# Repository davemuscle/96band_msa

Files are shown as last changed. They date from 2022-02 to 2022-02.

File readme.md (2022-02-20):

# 96 Note Music Spectrum Analyzer - FPGA

GIF

*Migrated to Git on February 20th, 2022. Updated web page on July 5th, 2020. Original release in
April 2020.*

This project converts your audio into a frequency spectrum and displays it on a VGA monitor in
real-time. The spectrum is mapped to all 96 half-notes in the first eight octaves, and is tuned to
A4 (440 Hz). It provides a visible output of 1920x1080 pixels at 60FPS, including multiple color
palette choices. There is also a choice between using an onboard microphone with auto gain control,
or a line-level input output pair.

All of the code was written in VHDL on an Artix-7. The main DSP technique used was multi-resolution,
constant-Q analysis. A custom PCB was designed at the end of project.

The general timeframe was between December 2019 and April 2020. This includes multiple rewrites of
the entire VHDL codebase, multiple hardware choice changes, and the design of the website.

## Demonstration
CTRL+click the video thumbnails to open in a new tab

| Youtube Videos |
| :--: |
| *Music Spectrum Analyzer - OSRS Harmony* |
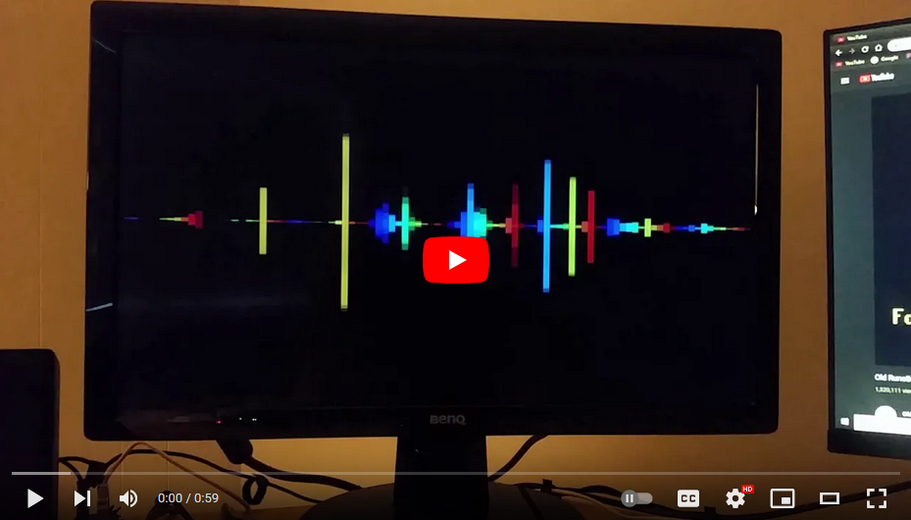
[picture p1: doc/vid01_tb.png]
(https://youtu.be/-Q9aSZRLyek)
|  |
| *Music Spectrum Analyzer - Ave Maria* |
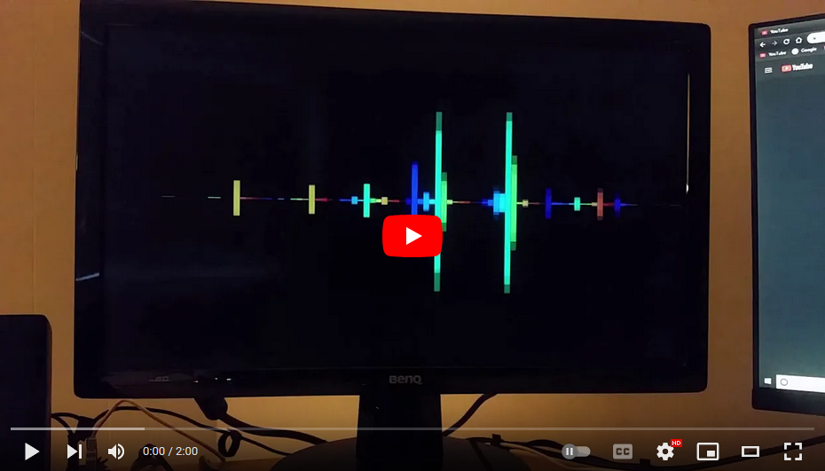
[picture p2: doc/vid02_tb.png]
(https://youtu.be/DIGgBtx7Qf0)
|  |
| *Music Spectrum Analyzer - Davy Jones Theme* |
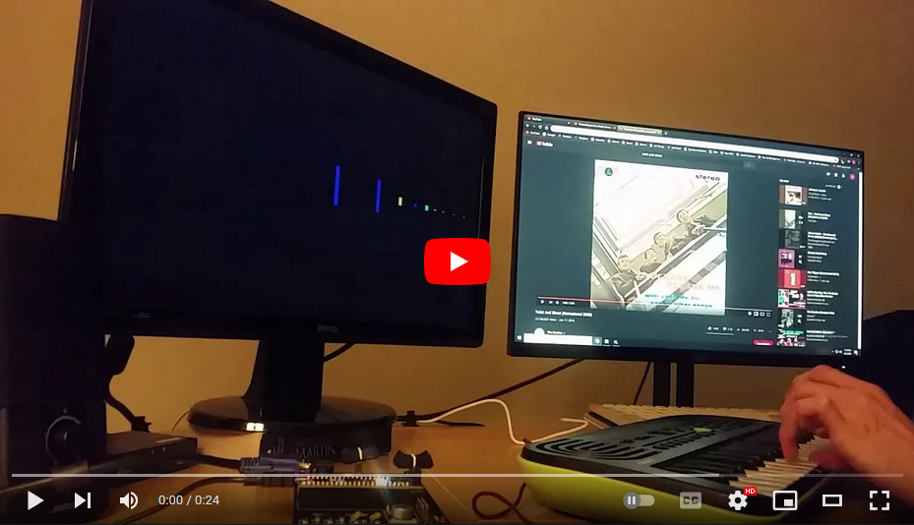
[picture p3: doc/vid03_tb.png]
(https://youtu.be/745tQkoyp0c)
|  |

## Implementation
### Hardware Block Diagram

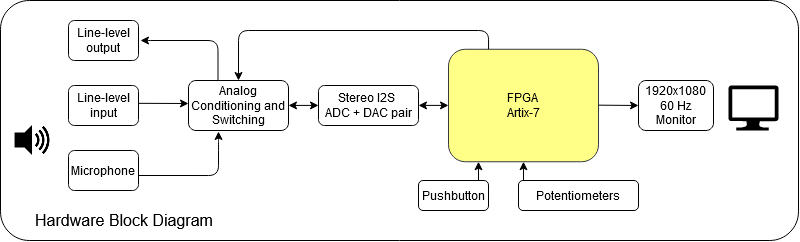
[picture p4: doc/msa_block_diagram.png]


### Printed Circuit Board

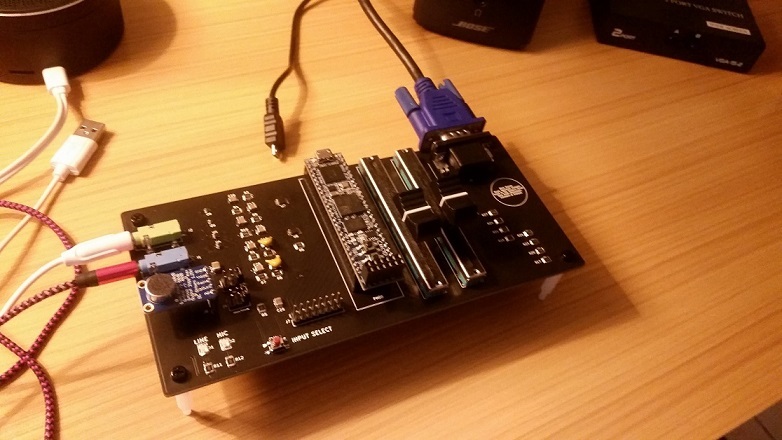
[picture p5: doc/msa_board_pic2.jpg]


### FPGA Design

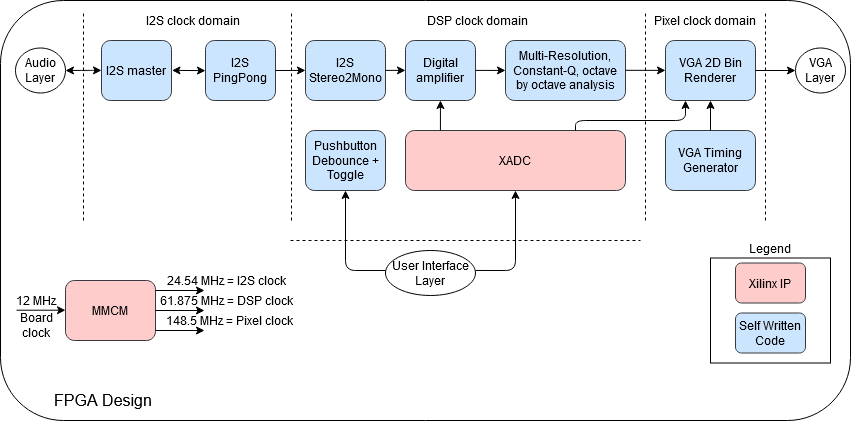
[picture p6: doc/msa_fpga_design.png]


#### Sub-designs
- I2S Master
    - Interface to I2S audio layer, reads and writes one sample of sound.
- I2S PingPong
    - Buffers up a selectable amount of audio in ping-pong fashion. Allows reading and writing
      blocks of sound to the audio layer.
- I2S Stereo2Mono
    - Converts stereo audio to mono audio
- Digital Amplifier
    - Multiplies sound data by a scalar factor based on XADC input
- Multi-Resolution Analysis
    - See below
- VGA Timing Generator
    - Creates sync signals based on screen resolution and framerate.
- VGA 2D Bin Renderer
    - Draws the frequency spectrum on the screen

### DSP Processing

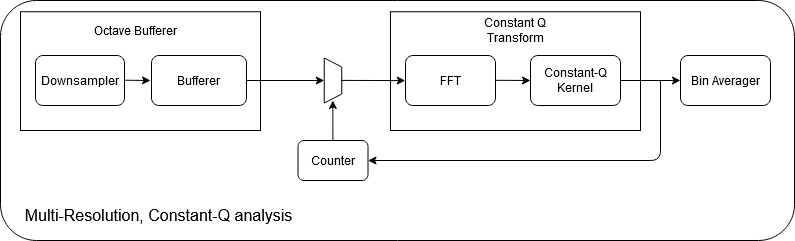
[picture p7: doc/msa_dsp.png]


The first portion of the DSP process downsamples the mono audio at 48 kHz into 8 separate octaves.
The downsampled data is buffered up, and a 256-point FFT followed by a Constant-Q transform is
performed on each octave. This downsampling and buffering is what gives us the "multi-resolution"
part of the project. The resulting frequency bins are averaged together to match the monitor's
refresh rate.

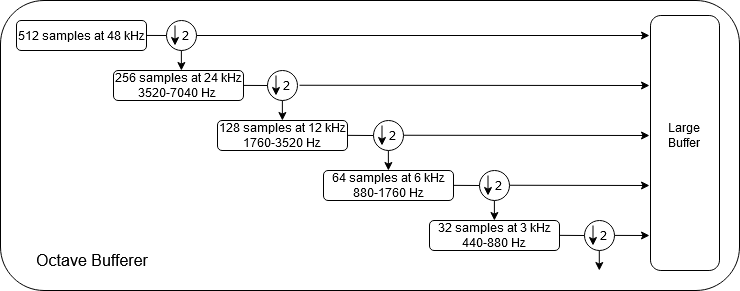
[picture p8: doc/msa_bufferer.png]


Above is the diagram for the octave bufferer. 512 samples at 48 kHz are sequentially downsampled
until we get to the loweset octave of interest.

### Reasoning behind Multi-Resolution Analysis

We actually perceive sound on a logarithmic scale, and we already are using multi-resolution
analysis! Our ears naturally have good time-localization for high-frequency sounds, and good frequency
resolution for low-frequency sounds. This means we can better determine when high-frequency sounds 
occur (time localization) and we can better distinguish between low frequency sounds (frequency resolution).

Check out the time-frequency tiling diagram:

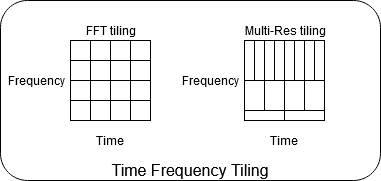
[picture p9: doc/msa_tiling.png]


The x-axis for each box represents a slice of time over which an FFT or some other process is
performed. The y-axis represents the frequency resolution for that time chunk.

The left diagram is how most spectrum analyzers are made -- with just an FFT. All of the tiles have
constant frequency and time resolution. 

The right is how I designed mine, attempting to match how we hear. Recording more samples allows for
a greater frequency resolution, but at the cost of higher latency. This means the lower frequencies
on the screen won't be as responsive as the higher frequencies.

The benefit to downsampling and processing multiple octaves separately is that the same sized FFT
can be used for each octave, and resources aren't wasted on the higher frequencies.

### Reasoning behind the Constant-Q Transform

Take a look at the difference in the piano keys below:

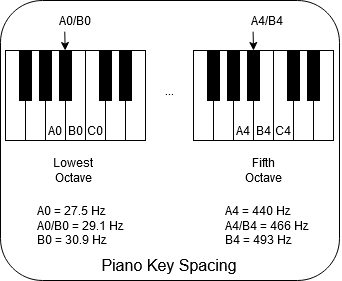
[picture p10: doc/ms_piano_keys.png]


The difference between the two lowest notes on an 88-key piano is only 1.6Hz, but for the fifth
octave, the difference in the lowest notes is 26 Hz!

This is because musical notes are logarithmically spaced, just like our hearing.
Each note can be obtained from another note by multiplying by a factor of 2^(1/12).

An FFT isn't great for this, since the frequency bins are arithmetically spaced (50 Hz, 100 Hz, ...)
The Constant-Q transform IS great for this, since we can specify a geometric scale to output our
bins.

The efficient implementation of the Constant-Q transform is pretty straight forward:
Generate the kernel for the transform (a sparse matrix of    coefficients, can be done before
run-time)
Take the FFT of your data 
Apply the generated kernel (this is just a matrix-multiply)

I pasted the code for the direct form of the Constant-Q transform below. If you interested in the
efficient implementation, check out the references.

### MATLAB Code for the Constant-Q Transform (Direct-Form)
```
%input setup
fs = 4000;                         %sample rate
note = 440;                        %note frequency, A4
input = cos(2*pi*note*(0:511)/fs); %pure tone input

%fft setup
fft_output = zeros(1, length(input)); %output vector
N = length(input);                    %size

%fft direct form = dft (slow)
for k = 0:N-1
    fft_output(k+1) = input * exp(-2*pi*1i*k*(0:N-1)'/N); %complex mult + LUT
end

%cqt setup
minimum_freq = 220;                                        %two full octaves are specified between
maximum_freq = 880;                                        %the min and the max frequencies
bins_per_octave = 12;                                      %12 bins per octave = 1 bin for 1 note
Q = 1/(2^(1/bins_per_octave)-1);                           %Q factor of the filterbank
K = ceil(bins_per_octave*log2(maximum_freq/minimum_freq)); %total num bins
cqt_output = zeros(1,K);

%cqt direct form
%this is the slow way to calculate the cqt
for k = 1:K
   N = round(Q*fs/(minimum_freq*2^((k-1)/bins_per_octave)));    %variable length
   cqt_output(k) = cqt_input(1:N) * exp(-2*pi*1i*Q*(0:N-1)'/N); %same form as fft
end

%plots of obtained data obtained
close all;
figure %only plotting one image of the spectrum
stem(abs(fft_output(1:length(input)/2)))
title('fft output');
ylabel('magnitude');
xlabel('bin');
figure
stem(abs(cqt_output))
title('cqt output');
ylabel('magnitude');
xlabel('bin');
```
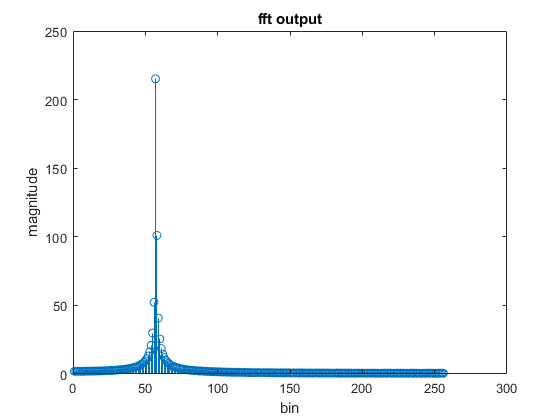
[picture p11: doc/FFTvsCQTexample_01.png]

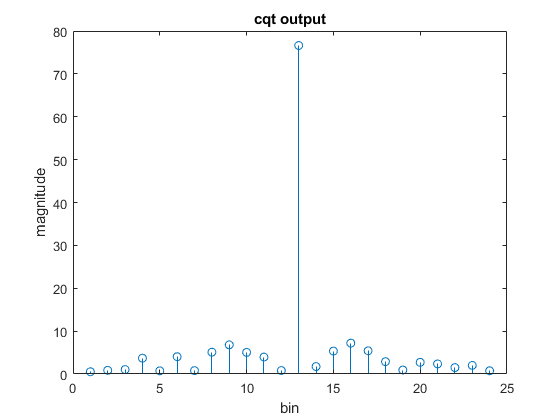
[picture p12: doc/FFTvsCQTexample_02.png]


### References
1. [Piano Key Frequencies](https://en.wikipedia.org/wiki/Piano_key_frequencies)
2. [Benjamin Blankertz, Constant-Q Transform](http://doc.ml.tu-berlin.de/bbci/material/publications/Bla_constQ.pdf)
3. [Brown & Puckette , Effecient Constant-Q Transform](http://academics.wellesley.edu/Physics/brown/pubs/effalgV92P2698-P2701.pdf)
4. [Djikstra's Square Root Algorithm](http://lib.tkk.fi/Diss/2005/isbn9512275279/article3.pdf)
5. [VGA Timing](https://projectf.io/posts/video-timings-vga-720p-1080p/)
6. [Artix 7 Board](https://digilent.com/shop/cmod-a7-breadboardable-artix-7-fpga-module/)
7. [Website Inspiration, 96khz.org](http://www.96khz.org/projects.htm)

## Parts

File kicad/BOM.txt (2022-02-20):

Components per board:

Core
	1 CMOD A7

Mechanical

	2 Slidepots
	1 Push button
	4 Mounting Pads

Capacitors (all 1210 - 3225 metric)
	14 	100 nF
	5  	10 uF
	6 	1 uF
	2 	3.3 uF
	2 	180 pF
	2	2.7 nF
	1	100 uF
	
Resistors (all 1210 - 3225 metric)
	6	4.7k
	4   	10k
	5 	470
	5	1k
	3	2.2K

LEDs (all 1210 - 3225 metric)
	2 	LEDs (blue?)
	
ICs
	1	3.3V voltage reg
	4	analog switches
	1 	adc
	1	dac

Connectors
	2 	Audio Jacks (1 green, 1 blue)
	Assortment of cuttable male and female headers
	1	VGA DB15

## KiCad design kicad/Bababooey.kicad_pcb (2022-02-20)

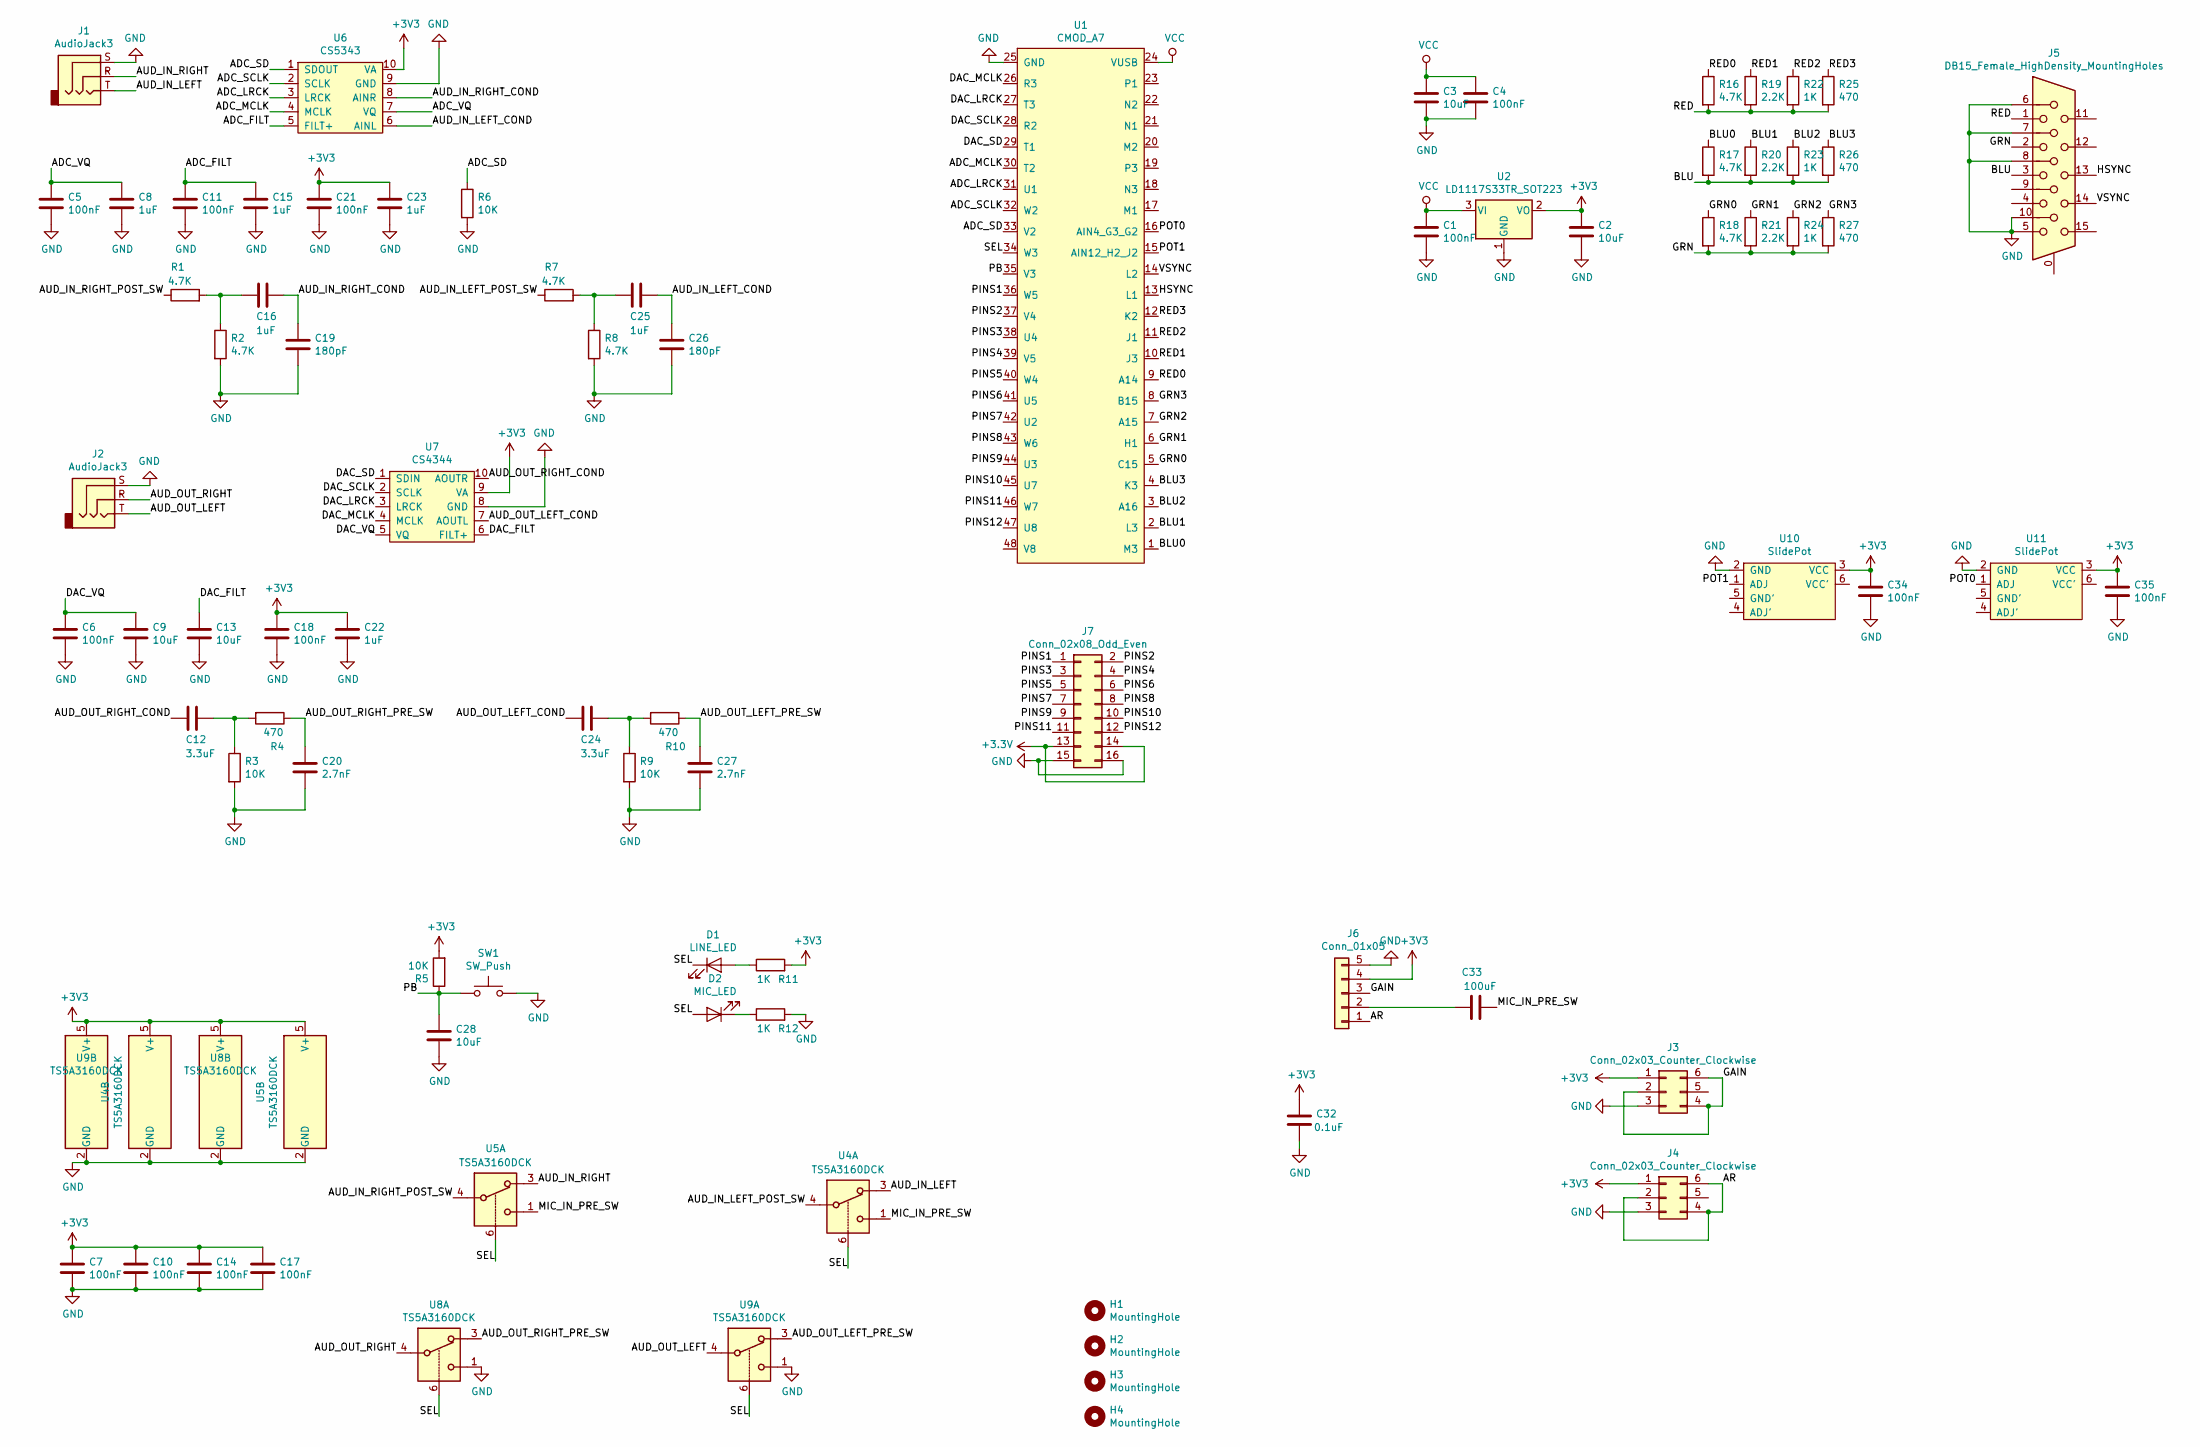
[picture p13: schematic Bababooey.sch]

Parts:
C1, C4, C5, C6, C7, C10, C11, C14, C17, C18, C21, C34, C35: 100nF; C_1210_3225Metric_Pad1.42x2.65mm_HandSolder
C2, C3, C9, C13, C28: 10uF; C_1210_3225Metric_Pad1.42x2.65mm_HandSolder
C8, C15, C16, C22, C23, C25: 1uF; C_1210_3225Metric_Pad1.42x2.65mm_HandSolder
C12, C24: 3.3uF; C_1210_3225Metric_Pad1.42x2.65mm_HandSolder
C19, C26: 180pF; C_1210_3225Metric_Pad1.42x2.65mm_HandSolder
C20, C27: 2.7nF; C_1210_3225Metric_Pad1.42x2.65mm_HandSolder
C32: 0.1uF; C_1210_3225Metric_Pad1.42x2.65mm_HandSolder
C33: 100uF; C_1210_3225Metric_Pad1.42x2.65mm_HandSolder
D1: LINE_LED; LED_1210_3225Metric_Pad1.42x2.65mm_HandSolder
D2: MIC_LED; LED_1210_3225Metric_Pad1.42x2.65mm_HandSolder
H1, H2, H3, H4: MountingHole; MountingHole_3.5mm
J1, J2: AudioJack3; Jack_3.5mm_CUI_SJ-3524-SMT_Horizontal
J3, J4: Conn_02x03_Counter_Clockwise; PinHeader_2x03_P2.54mm_Vertical
J5: DB15_Female_HighDensity_MountingHoles; DSUB-15-HD_Female_Horizontal_P2.29x1.98mm_EdgePinOffset8.35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
J6: Conn_01x05; PinSocket_1x05_P2.54mm_Vertical
J7: Conn_02x08_Odd_Even; PinSocket_2x08_P2.54mm_Vertical
R1, R2, R7, R8, R16, R17, R18: 4.7K; R_1210_3225Metric_Pad1.42x2.65mm_HandSolder
R3, R5, R6, R9: 10K; R_1210_3225Metric_Pad1.42x2.65mm_HandSolder
R4, R10, R25, R26, R27: 470; R_1210_3225Metric_Pad1.42x2.65mm_HandSolder
R11, R12, R22, R23, R24: 1K; R_1210_3225Metric_Pad1.42x2.65mm_HandSolder
R19, R20, R21: 2.2K; R_1210_3225Metric_Pad1.42x2.65mm_HandSolder
SW1: SW_Push; SW_SPST_TL3305B
U1: CMOD_A7
U2: LD1117S33TR_SOT223; SOT-223-3_TabPin2
U4, U5, U8, U9: TS5A3160DCK; SOT-363_SC-70-6
U6: CS5343; TSSOP-10_3x3mm_P0.5mm
U7: CS4344; TSSOP-10_3x3mm_P0.5mm
U10, U11: SlidePot

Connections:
/ADC_FILT: C11.1, C15.1, U6.5 (FILT+)
/ADC_LRCK: U1.31 (U1), U6.3 (LRCK)
/ADC_MCLK: U1.30 (T2), U6.4 (MCLK)
/ADC_SCLK: U1.32 (W2), U6.2 (SCLK)
/ADC_SD: R6.1, U1.33 (V2), U6.1 (SDOUT)
/ADC_VQ: C5.1, C8.1, U6.7 (VQ)
/AR: J4.2, J4.4, J4.6, J6.1
/AUD_IN_LEFT: J1.T, U4.3
/AUD_IN_LEFT_COND: C25.1, C26.1, U6.6 (AINL)
/AUD_IN_LEFT_POST_SW: R7.1, U4.4
/AUD_IN_RIGHT: J1.R, U5.3
/AUD_IN_RIGHT_COND: C16.1, C19.1, U6.8 (AINR)
/AUD_IN_RIGHT_POST_SW: R1.1, U5.4
/AUD_OUT_LEFT: J2.T, U9.4
/AUD_OUT_LEFT_COND: C24.2, U7.7 (AOUTL)
/AUD_OUT_LEFT_PRE_SW: C27.1, R10.1, U9.3
/AUD_OUT_RIGHT: J2.R, U8.4
/AUD_OUT_RIGHT_COND: C12.2, U7.10 (AOUTR)
/AUD_OUT_RIGHT_PRE_SW: C20.1, R4.1, U8.3
/BLU: J5.3, R17.2, R20.2, R23.2, R26.2
/BLU0: R17.1, U1.1 (M3)
/BLU1: R20.1, U1.2 (L3)
/BLU2: R23.1, U1.3 (A16)
/BLU3: R26.1, U1.4 (K3)
/DAC_FILT: C13.1, U7.6 (FILT+)
/DAC_LRCK: U1.27 (T3), U7.3 (LRCK)
/DAC_MCLK: U1.26 (R3), U7.4 (MCLK)
/DAC_SCLK: U1.28 (R2), U7.2 (SCLK)
/DAC_SD: U1.29 (T1), U7.1 (SDIN)
/DAC_VQ: C6.1, C9.1, U7.5 (VQ)
/GAIN: J3.2, J3.4, J3.6, J6.3
/GRN: J5.2, R18.2, R21.2, R24.2, R27.2
/GRN0: R18.1, U1.5 (C15)
/GRN1: R21.1, U1.6 (H1)
/GRN2: R24.1, U1.7 (A15)
/GRN3: R27.1, U1.8 (B15)
/HSYNC: J5.13, U1.13 (L1)
/MIC_IN_PRE_SW: C33.2, U4.1, U5.1
/PB: C28.1, R5.1, SW1.1, U1.35 (V3)
/PINS1: J7.1, U1.36 (W5)
/PINS2: J7.2, U1.37 (V4)
/PINS3: J7.3, U1.38 (U4)
/PINS4: J7.4, U1.39 (V5)
/PINS5: J7.5, U1.40 (W4)
/PINS6: J7.6, U1.41 (U5)
/PINS7: J7.7, U1.42 (U2)
/PINS8: J7.8, U1.43 (W6)
/PINS9: J7.9, U1.44 (U3)
/PINS10: J7.10, U1.45 (U7)
/PINS11: J7.11, U1.46 (W7)
/PINS12: J7.12, U1.47 (U8)
/POT0: U1.16 (AIN4_G3_G2), U11.1 (ADJ)
/POT1: U1.15 (AIN12_H2_J2), U10.1 (ADJ)
/RED: J5.1, R16.2, R19.2, R22.2, R25.2
/RED0: R16.1, U1.9 (A14)
/RED1: R19.1, U1.10 (J3)
/RED2: R22.1, U1.11 (J1)
/RED3: R25.1, U1.12 (K2)
/SEL: D1.1 (K), D2.2 (A), U1.34 (W3), U4.6, U5.6, U8.6, U9.6
/VSYNC: J5.14, U1.14 (L2)
GND: C1.2, C2.2, C3.2, C4.2, C5.2, C6.2, C7.2, C8.2, C9.2, C10.2, C11.2, C13.2, C14.2, C15.2, C17.2, C18.2, C19.2, C20.2, C21.2, C22.2, C23.2, C26.2, C27.2, C28.2, C32.2, C34.2, C35.2, J1.S, J2.S, J3.3, J4.3, J5.5, J5.6, J5.7, J5.8, J5.10, J6.5, J7.15, J7.16, R2.2, R3.2, R6.2, R8.2, R9.2, R12.2, SW1.2, U1.25 (GND), U2.1 (GND), U4.2 (GND), U5.2 (GND), U6.9 (GND), U7.8 (GND), U8.1, U8.2 (GND), U9.1, U9.2 (GND), U10.2 (GND), U11.2 (GND)
unnamed: C12.1, R3.1, R4.2
unnamed: C16.2, R1.2, R2.1
unnamed: C24.1, R9.1, R10.2
unnamed: C25.2, R7.2, R8.1
unnamed: C33.1, J6.2
unnamed: D1.2 (A), R11.1
unnamed: D2.1 (K), R12.1
VCC: C1.1, C3.1, C4.1, U1.24 (VUSB), U2.3 (VI)

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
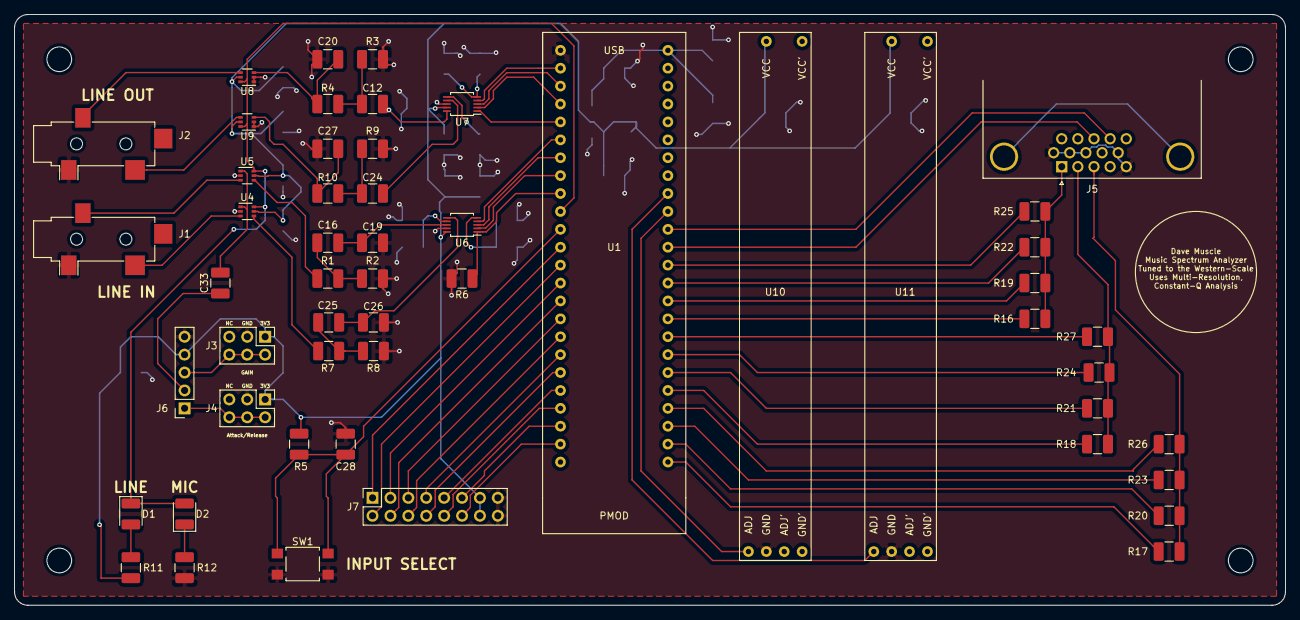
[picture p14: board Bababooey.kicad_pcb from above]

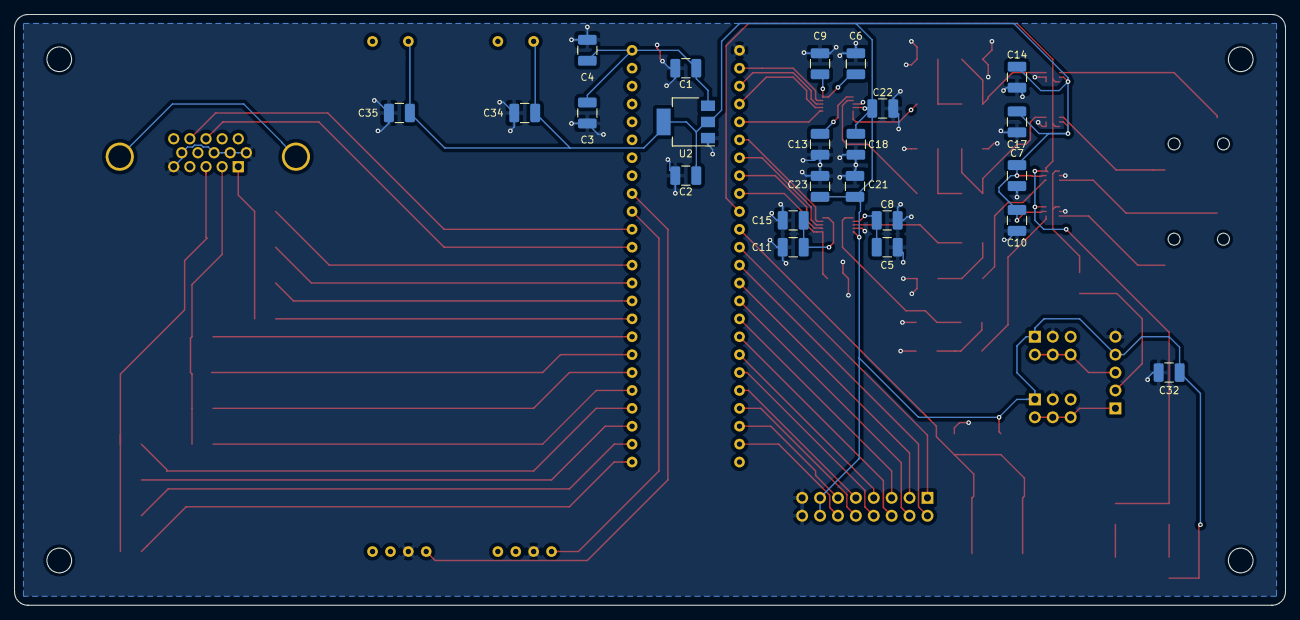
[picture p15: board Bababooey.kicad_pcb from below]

Board: 2 copper layers, 180.3 x 83.8 mm, 80 parts (23 on the bottom side), 70 nets.

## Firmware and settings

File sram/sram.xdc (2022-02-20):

## Cellular RAM
set_property -dict { PACKAGE_PIN M18   IOSTANDARD LVCMOS33 } [get_ports { MemAdr[0]  }]; #IO_L11P_T1_SRCC_14 Sch=sram- a[0]
set_property -dict { PACKAGE_PIN M19   IOSTANDARD LVCMOS33 } [get_ports { MemAdr[1]  }]; #IO_L11N_T1_SRCC_14 Sch=sram- a[1]
set_property -dict { PACKAGE_PIN K17   IOSTANDARD LVCMOS33 } [get_ports { MemAdr[2]  }]; #IO_L12N_T1_MRCC_14 Sch=sram- a[2]
set_property -dict { PACKAGE_PIN N17   IOSTANDARD LVCMOS33 } [get_ports { MemAdr[3]  }]; #IO_L13P_T2_MRCC_14 Sch=sram- a[3]
set_property -dict { PACKAGE_PIN P17   IOSTANDARD LVCMOS33 } [get_ports { MemAdr[4]  }]; #IO_L13N_T2_MRCC_14 Sch=sram- a[4]
set_property -dict { PACKAGE_PIN P18   IOSTANDARD LVCMOS33 } [get_ports { MemAdr[5]  }]; #IO_L14P_T2_SRCC_14 Sch=sram- a[5]
set_property -dict { PACKAGE_PIN R18   IOSTANDARD LVCMOS33 } [get_ports { MemAdr[6]  }]; #IO_L14N_T2_SRCC_14 Sch=sram- a[6]
set_property -dict { PACKAGE_PIN W19   IOSTANDARD LVCMOS33 } [get_ports { MemAdr[7]  }]; #IO_L16N_T2_A15_D31_14 Sch=sram- a[7]
set_property -dict { PACKAGE_PIN U19   IOSTANDARD LVCMOS33 } [get_ports { MemAdr[8]  }]; #IO_L15P_T2_DQS_RDWR_B_14 Sch=sram- a[8]
set_property -dict { PACKAGE_PIN V19   IOSTANDARD LVCMOS33 } [get_ports { MemAdr[9]  }]; #IO_L15N_T2_DQS_DOUT_CSO_B_14 Sch=sram- a[9]
set_property -dict { PACKAGE_PIN W18   IOSTANDARD LVCMOS33 } [get_ports { MemAdr[10] }]; #IO_L16P_T2_CSI_B_14 Sch=sram- a[10]
set_property -dict { PACKAGE_PIN T17   IOSTANDARD LVCMOS33 } [get_ports { MemAdr[11] }]; #IO_L17P_T2_A14_D30_14 Sch=sram- a[11]
set_property -dict { PACKAGE_PIN T18   IOSTANDARD LVCMOS33 } [get_ports { MemAdr[12] }]; #IO_L17N_T2_A13_D29_14 Sch=sram- a[12]
set_property -dict { PACKAGE_PIN U17   IOSTANDARD LVCMOS33 } [get_ports { MemAdr[13] }]; #IO_L18P_T2_A12_D28_14 Sch=sram- a[13]
set_property -dict { PACKAGE_PIN U18   IOSTANDARD LVCMOS33 } [get_ports { MemAdr[14] }]; #IO_L18N_T2_A11_D27_14 Sch=sram- a[14]
set_property -dict { PACKAGE_PIN V16   IOSTANDARD LVCMOS33 } [get_ports { MemAdr[15] }]; #IO_L19P_T3_A10_D26_14 Sch=sram- a[15]
set_property -dict { PACKAGE_PIN W16   IOSTANDARD LVCMOS33 } [get_ports { MemAdr[16] }]; #IO_L20P_T3_A08_D24_14 Sch=sram- a[16]
set_property -dict { PACKAGE_PIN W17   IOSTANDARD LVCMOS33 } [get_ports { MemAdr[17] }]; #IO_L20N_T3_A07_D23_14 Sch=sram- a[17]
set_property -dict { PACKAGE_PIN V15   IOSTANDARD LVCMOS33 } [get_ports { MemAdr[18] }]; #IO_L21P_T3_DQS_14 Sch=sram- a[18]
set_property -dict { PACKAGE_PIN W15   IOSTANDARD LVCMOS33 } [get_ports { MemDB[0]   }]; #IO_L21N_T3_DQS_A06_D22_14 Sch=sram-dq[0]
set_property -dict { PACKAGE_PIN W13   IOSTANDARD LVCMOS33 } [get_ports { MemDB[1]   }]; #IO_L22P_T3_A05_D21_14 Sch=sram-dq[1]
set_property -dict { PACKAGE_PIN W14   IOSTANDARD LVCMOS33 } [get_ports { MemDB[2]   }]; #IO_L22N_T3_A04_D20_14 Sch=sram-dq[2]
set_property -dict { PACKAGE_PIN U15   IOSTANDARD LVCMOS33 } [get_ports { MemDB[3]   }]; #IO_L23P_T3_A03_D19_14 Sch=sram-dq[3]
set_property -dict { PACKAGE_PIN U16   IOSTANDARD LVCMOS33 } [get_ports { MemDB[4]   }]; #IO_L23N_T3_A02_D18_14 Sch=sram-dq[4]
set_property -dict { PACKAGE_PIN V13   IOSTANDARD LVCMOS33 } [get_ports { MemDB[5]   }]; #IO_L24P_T3_A01_D17_14 Sch=sram-dq[5]
set_property -dict { PACKAGE_PIN V14   IOSTANDARD LVCMOS33 } [get_ports { MemDB[6]   }]; #IO_L24N_T3_A00_D16_14 Sch=sram-dq[6]
set_property -dict { PACKAGE_PIN U14   IOSTANDARD LVCMOS33 } [get_ports { MemDB[7]   }]; #IO_25_14 Sch=sram-dq[7]
set_property -dict { PACKAGE_PIN P19   IOSTANDARD LVCMOS33 } [get_ports { RamOEn     }]; #IO_L10P_T1_D14_14 Sch=sram-oe
set_property -dict { PACKAGE_PIN R19   IOSTANDARD LVCMOS33 } [get_ports { RamWEn     }]; #IO_L10N_T1_D15_14 Sch=sram-we
set_property -dict { PACKAGE_PIN N19   IOSTANDARD LVCMOS33 } [get_ports { RamCEn     }]; #IO_L9N_T1_DQS_D13_14 Sch=sram-ce

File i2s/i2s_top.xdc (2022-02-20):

set_property PACKAGE_PIN T3 [get_ports dac_lrclk]
set_property PACKAGE_PIN R3 [get_ports dac_mclk]
set_property PACKAGE_PIN R2 [get_ports dac_sclk]
set_property PACKAGE_PIN T2 [get_ports adc_mclk]
set_property PACKAGE_PIN U1 [get_ports adc_lrclk]
set_property PACKAGE_PIN W2 [get_ports adc_sclk]
set_property PACKAGE_PIN T1 [get_ports sdout]
set_property PACKAGE_PIN V2 [get_ports sdin]
set_property IOSTANDARD LVCMOS33 [get_ports sdout]
set_property IOSTANDARD LVCMOS33 [get_ports sdin]
set_property IOSTANDARD LVCMOS33 [get_ports dac_sclk]
set_property IOSTANDARD LVCMOS33 [get_ports dac_mclk]
set_property IOSTANDARD LVCMOS33 [get_ports dac_lrclk]
set_property IOSTANDARD LVCMOS33 [get_ports adc_sclk]
set_property IOSTANDARD LVCMOS33 [get_ports adc_mclk]
set_property IOSTANDARD LVCMOS33 [get_ports adc_lrclk]
